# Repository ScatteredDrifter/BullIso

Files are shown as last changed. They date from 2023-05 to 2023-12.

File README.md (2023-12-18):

# BullIso

A replacement Board for the Bully, incorporating an ISO-Enter.
You can find the original bully [here](https://www.cbkbd.com/product/bully)

Yet another link to the project: [link](https://github.com/zhol0777/bully-files)

made by ScatteredDrifter ~Evelyn

---

Measurements for the pcb were taken from the available plate-files. 

---

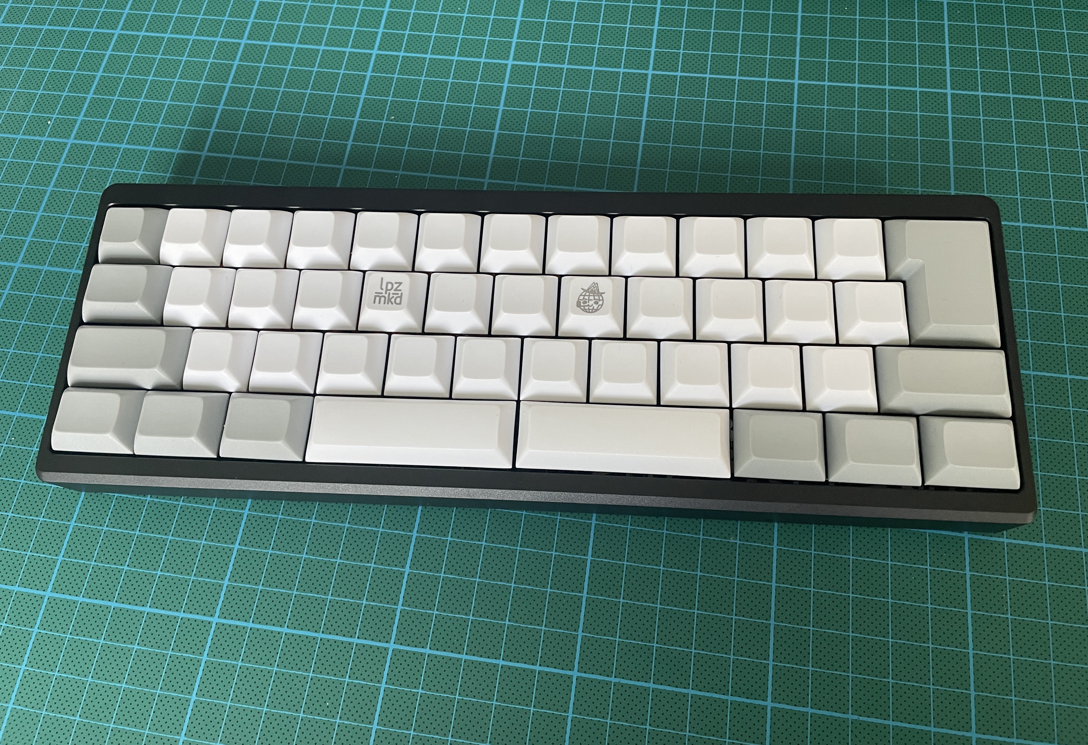
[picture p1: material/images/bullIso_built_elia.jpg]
image of built iso by Elia

Image by Elia, whom I designed this for.

## Current Status :
- prototypes produced and tested 
- working as intended

## Features : 
- Rp2040 with EEPROM 
- qmk / vial compatible 
- optional pinouts(3) for further tinkering / features
- daughterboard-Support 
- support for mx-switches 
- production files ready for JLCPCB

## Layout : 
All available layouts are to be seen in the following image: 

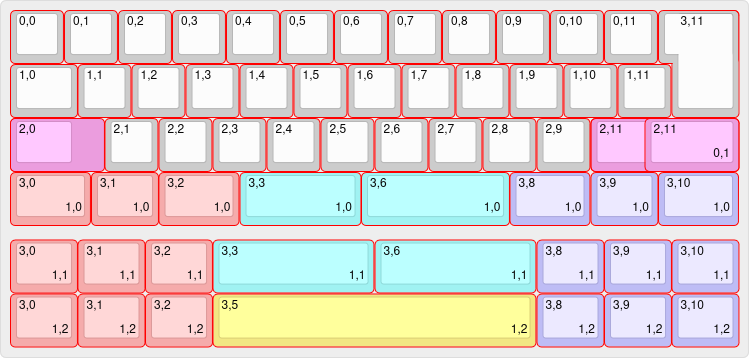
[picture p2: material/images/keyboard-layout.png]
image of available keyboard layouts


---

## Firmware ::
pre-compiled file for vial can be found in the **"/firmware"** section.
To enter the bootloader - which is necessary in order to flash a new firmware - press the button next to the encoder on the back of the pcb and plug-it into your keyboard while keeping the button pressed. It should show up as a regular usb-stick in your file explorer now and you can drag the .uf2 onto this usb-stick. Once done it will restart and use your newly flashed firmware!

## Building your own ::

On the verge to build this keyboard your own?
For building one yourself you require the following:
- this pcb
- a unified daughterboard ( the old version with Jst-connectors)
- the correct case 
- tadpole mounds ( just like for the original pcb)

### Getting PCBs ::
I've ordered my prototypes at **JLCPCB** because they are easy work with and I've had my previous projects manufactured there. This is not an advertisement neither do I enforce the use of this vendor's service. 

As of now the gerber-, BOM-, and Position-files are tailored towards the use with **JLCPCB**. 
All of them can be found in the following directory: 
- `production/assembly` for both BOM and Positions 
- `production/gerber` for the gerber files 

I usually use JLCPCB for my prototypes, the procedure should be fairly similiar for other manufacturers however, and they require the bulliso_pcb_gerber.zip, which can be found in **/production** and for assembly of all SMD-components also their positions (pcb-bottom-pos.csv) and the BOM (BOM_pcb.csv) all of which can be found in the **/production/assembly** directory.

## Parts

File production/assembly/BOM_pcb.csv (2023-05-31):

Comment | Designator | Footprint | LCSC
10u | C1,C4,C17 | Capacitor_SMD:C_0805_2012Metric | C91245
22pf | C2,C3 | Capacitor_SMD:C_0805_2012Metric | C1804
100n | C5,C6,C7,C9,C11,C12,C13,C14 | Capacitor_SMD:C_0805_2012Metric | C49678
1u | C8,C10 | Capacitor_SMD:C_0805_2012Metric | C28323
BAV70 | D1,D2,D3,D4,D5,D6,D7,D8,D9,D10,D11,D12,D13,D14,D15,D16,D17,D18,D19,D20,D21,D22,D23 | Package_TO_SOT_SMD:SOT-23 | C68978
BREAKOUT | J1 | Connector_PinSocket_2.54mm:PinSocket_1x05_P2.54mm_Vertical
Conn_01x03_Male | J2 | Connector_PinSocket_2.54mm:PinSocket_1x03_P2.54mm_Vertical
Conn_01x04_Female | J3 | random-keyboard-parts:JST-SR-4
3x Breakout | additional pins | J4 | Connector_PinHeader_2.54mm:PinHeader_1x03_P2.54mm_Vertical
Breakout 1.1v | J5 | Connector_PinHeader_2.54mm:PinHeader_1x02_P2.54mm_Vertical
1k | R1,R5 | Resistor_SMD:R_0805_2012Metric | C115316
27 | R3,R4 | Resistor_SMD:R_0805_2012Metric | C104170
10k | R8 | Resistor_SMD:R_0805_2012Metric | C115309
MX_stab | S1 | marbastlib-mx:STAB_MX_P_2u
MX_stab | S3,S7 | marbastlib-mx:STAB_MX_P_3u
MX_stab | S4 | marbastlib-mx:STAB_MX_P_2.25u
MX_stab | S5 | marbastlib-mx:STAB_MX_6u
MX_stab | S6 | marbastlib-mx:STAB_MX_6.25u
MX_stab | S8 | marbastlib-mx:STAB_MX_P_2.75u
2.25 | SW17 | marbastlib-mx:SW_MX_1u
MX_SW_solder | SW2,SW3,SW12,SW44,SW57 | marbastlib-mx:SW_MX_1.5u
3 | SW21,SW29 | marbastlib-mx:SW_MX_1u
2.75 | SW25 | marbastlib-mx:SW_MX_1u
6u | SW34 | marbastlib-mx:SW_MX_1u
MX_SW_solder | SW4 | marbastlib-mx:SW_MX_1.75u_stp
MX_SW_solder | SW5,SW8,SW9,SW10,SW13,SW14,SW15,SW18,SW19,SW20,SW22,SW23,SW24,SW26,SW27,SW28,SW31,SW32,SW33,SW35,SW36,SW37,SW38,SW39,SW40,SW41,SW42,SW43,SW46,SW47,SW48,SW5_1,SW52,SW58,SW61 | marbastlib-mx:SW_MX_1u
MX_SW_solder | SW53 | marbastlib-mx:SW_MX_1.75u
MX_SW_solder | SW6,SW7,SW11,SW16,SW49,SW50,SW55,SW59,SW60 | marbastlib-mx:SW_MX_1.25u
RESET | SW9998 | Keebio-Parts:SW_SPST_TL3342 | C2886894
RESET | SW9999 | Keebio-Parts:SW_SPST_TL3342 | C2886894
W25Q128JVS | U2 | Package_SO:SOIC-8_5.23x5.23mm_P1.27mm | C97521
RP2040 | U3 | RP2040:RP2040-QFN-56 | C2040
XC6206P Smaller footprint, less mA ~.5 | U4 | Package_TO_SOT_SMD:SOT-23 | C347376
12MHZ Crystal | Y0 | Crystal:Crystal_SMD_3225-4Pin_3.2x2.5mm | C9002

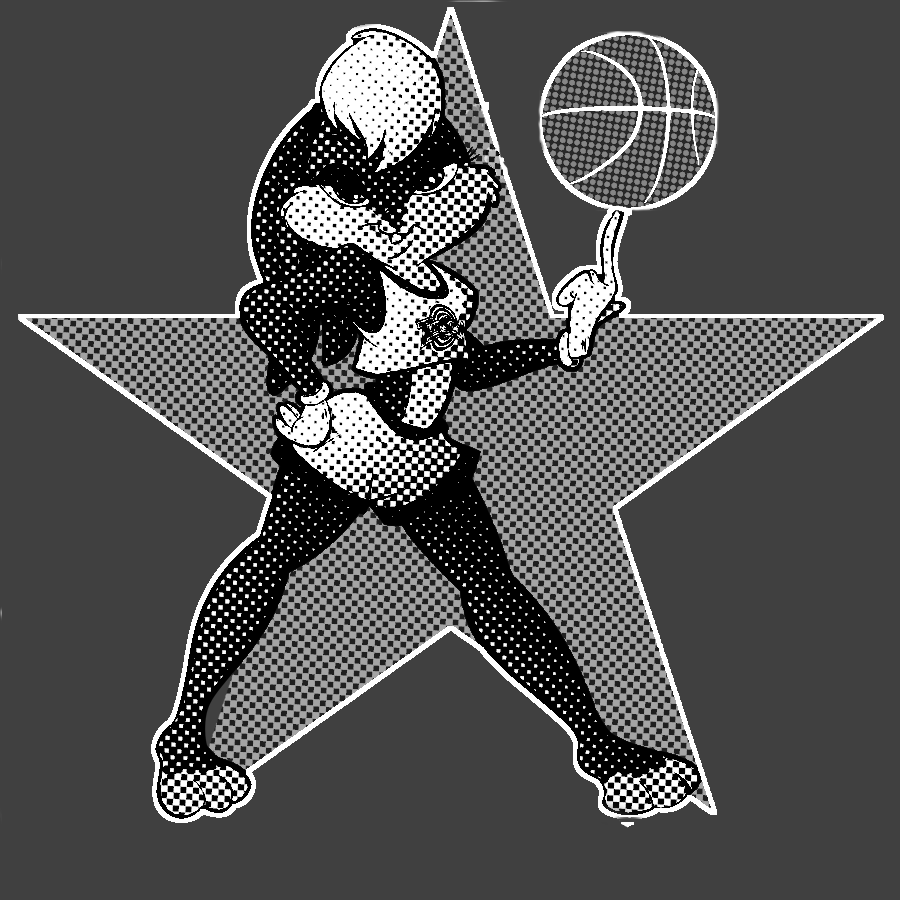
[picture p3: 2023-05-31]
material/layouts/daffycutoutBnW.png

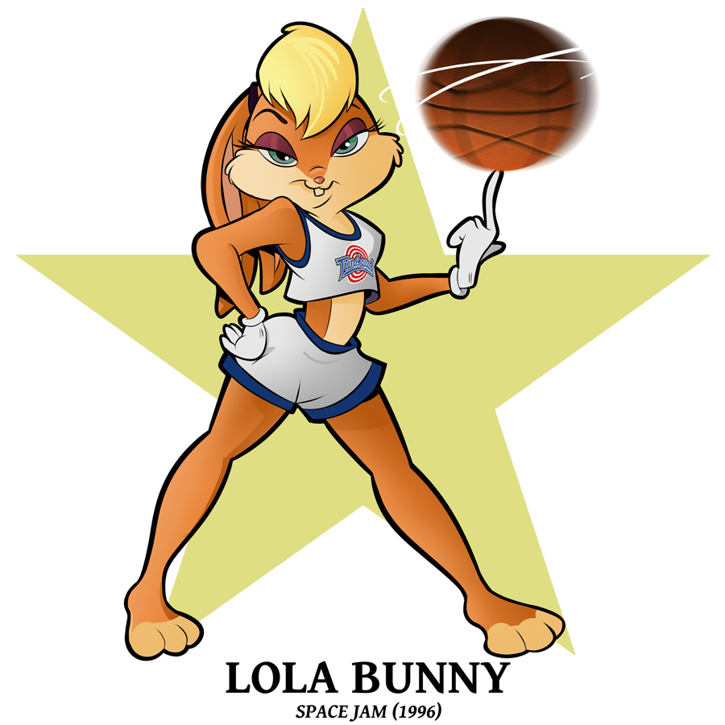
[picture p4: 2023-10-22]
material/layouts/lola.png

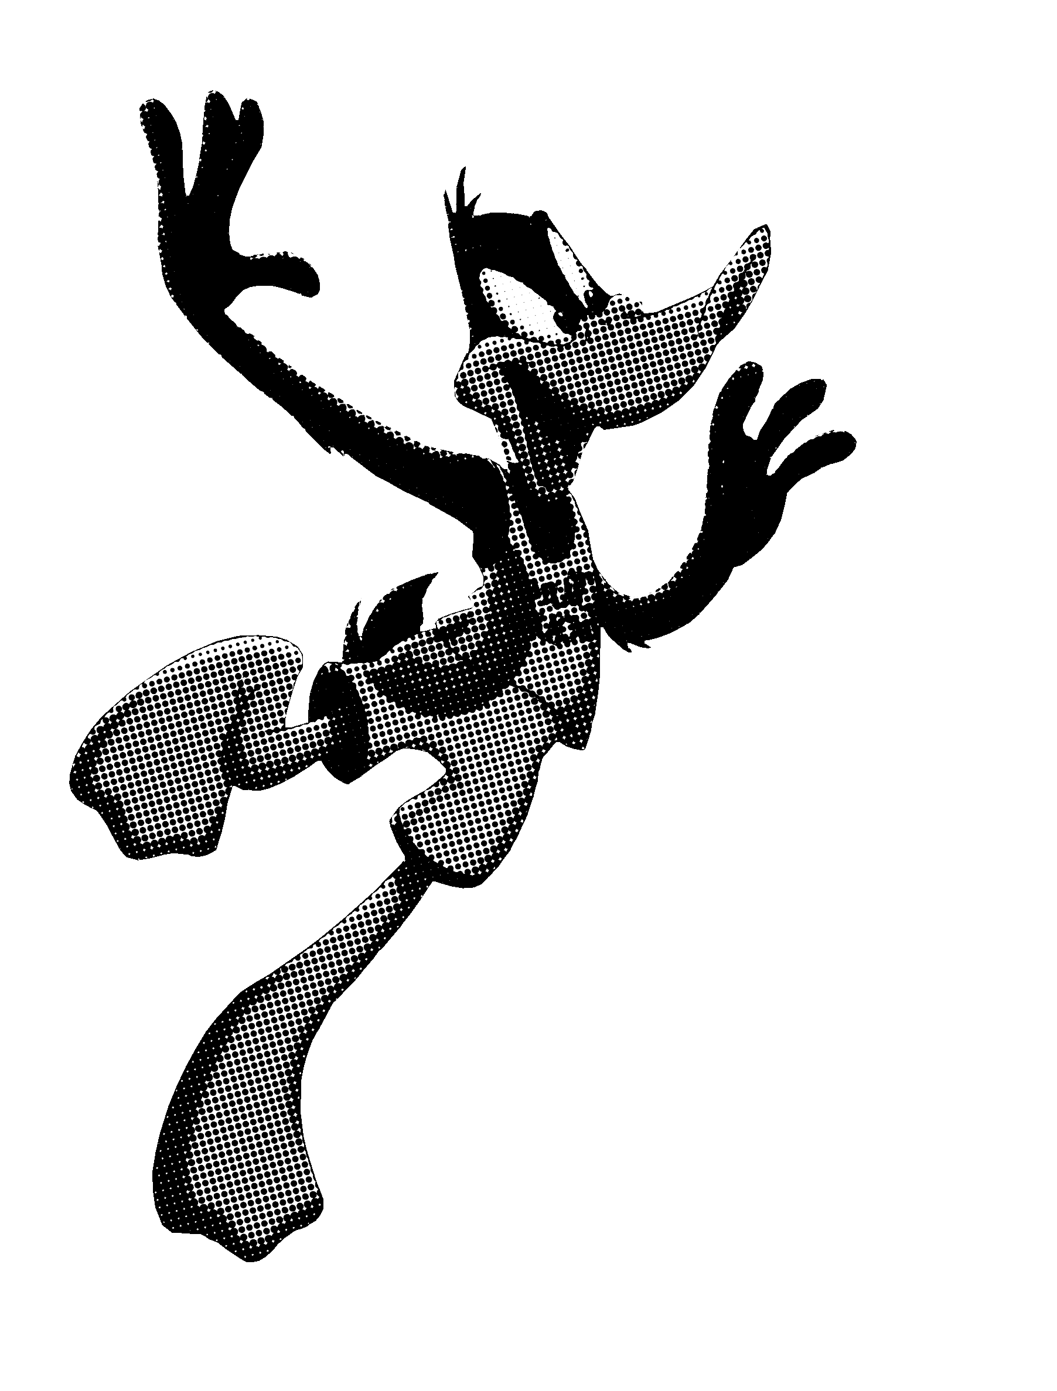
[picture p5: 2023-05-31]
material/layouts/daffycutoutBnW-flipped.png

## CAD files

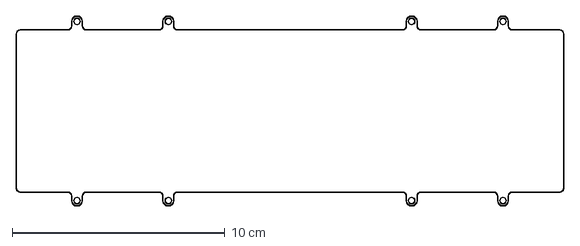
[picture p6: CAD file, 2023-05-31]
pcb/edgecuts.dxf
25.7 x 8.92 cm

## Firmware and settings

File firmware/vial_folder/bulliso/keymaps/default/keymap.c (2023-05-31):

/* Derivate of elmo's firmware >>kb-elmo<mail@elmo.space>
 *
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
 * You should have received a copy of the GNU General Public License
 * along with this program.  If not, see <http://www.gnu.org/licenses/>.
 */
#include QMK_KEYBOARD_H

// defining layer_names 
#define _BL 0
#define _FL 1
#define _FFL 2
#define ____ KC_NO

// --- /
// -- / definition of  encoder map
#if defined(ENCODER_MAP_ENABLE)
const uint16_t PROGMEM encoder_map[][NUM_ENCODERS][2] = {
    [0] =   { ENCODER_CCW_CW(KC_MS_WH_UP, KC_MS_WH_DOWN), ENCODER_CCW_CW(KC_VOLD, KC_VOLU)  },
    [1] =  { ENCODER_CCW_CW(RGB_HUD, RGB_HUI),           ENCODER_CCW_CW(RGB_SAD, RGB_SAI)  },
    [2] =  { ENCODER_CCW_CW(RGB_VAD, RGB_VAI),           ENCODER_CCW_CW(RGB_SPD, RGB_SPI)  },
    [3] = { ENCODER_CCW_CW(RGB_RMOD, RGB_MOD),          ENCODER_CCW_CW(KC_RIGHT, KC_LEFT) }
};
#endif
const uint16_t PROGMEM keymaps[][MATRIX_ROWS][MATRIX_COLS] = {


   [_BL] = LAYOUT(
            
        ____,    	____,    	____,    	____,    	____,  		____,    	____,    	____,    	____,    	____,    	____,   ____,  
        ____,    	____,    	____,    	____,    	____,  		____,    	____,    	____,    	____,    	____,       ____,   ____,   
        ____,    	____,    	____,    	____,    	____,  		____,    	____,    	____,    	____,    	____,    	____,   ____,
        ____,    	____,    	____,    	____,    	            ____,       ____,    	        	____,    	____,       ____,   ____

    ),
};

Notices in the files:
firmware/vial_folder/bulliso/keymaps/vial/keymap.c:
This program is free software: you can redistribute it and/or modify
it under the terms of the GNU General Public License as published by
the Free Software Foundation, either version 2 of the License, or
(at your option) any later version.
